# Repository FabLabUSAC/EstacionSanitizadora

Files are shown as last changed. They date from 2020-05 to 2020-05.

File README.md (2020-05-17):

# EstacionSanitizadora
EL objetivo es brindar un debido proceso de sanitizacion en las entradas de edificion concurridos, esto de manera automatizada para evitar que las personas infrijan las medidas de seguridad sanitarias establecidas por el evento actual de la pandemia del COVID-19.
En la contruccion final del prototipo se utilizaron los siguientes materiales:

2 puentes H L298N
Arduino Mega ADK
Lcd 16x2 con interfaz I2C serial
Fuente de 12V 5A
4 metros de tiras led verdes de exterior
4 metros de tiras led rojas de exterior
1 sensor ultrasonico hc-sr05
4 sensores de proximidad infrarrojos  
cable dupont macho macho, hembra hembra ,macho hembra
cable del calibre 22
Perfiles 20x20
Caja para proyectos
tornillos 3M
Tubo para cable

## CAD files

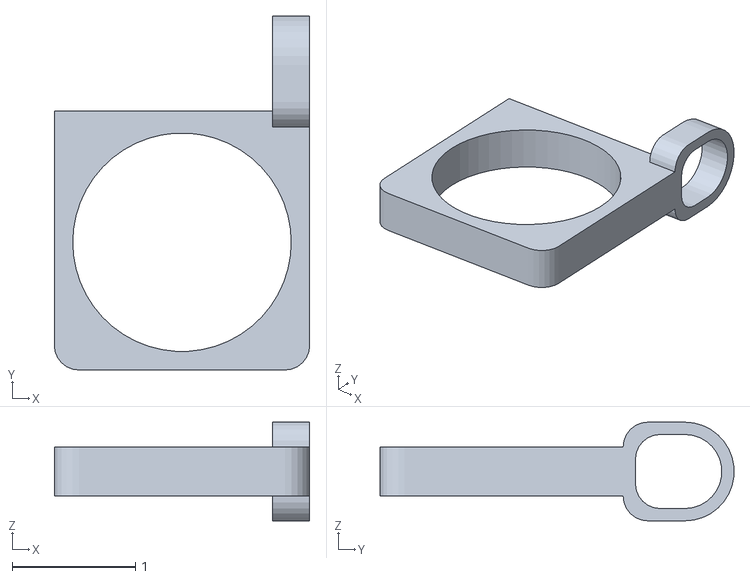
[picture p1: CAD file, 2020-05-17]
3D Files/Socket Sensor.stl
2.07 x 2.87 x 0.8

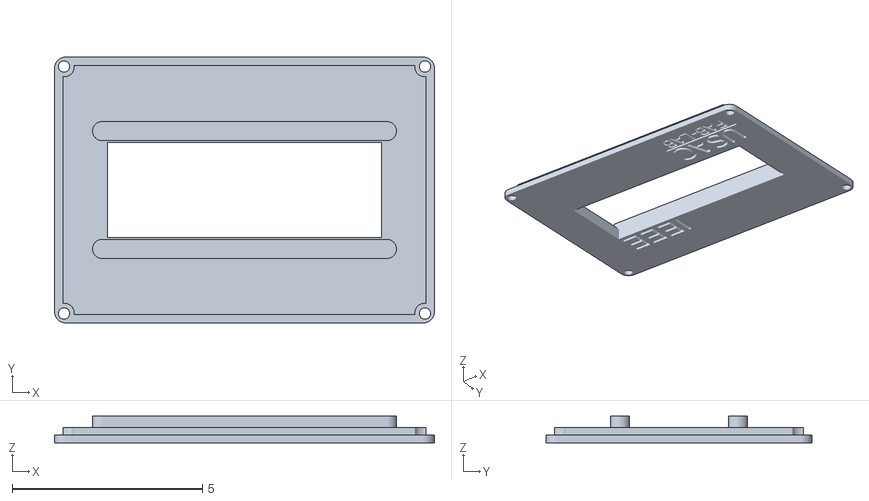
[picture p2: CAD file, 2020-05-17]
3D Files/Front_Box.stl
10.0 x 7.00 x 0.7

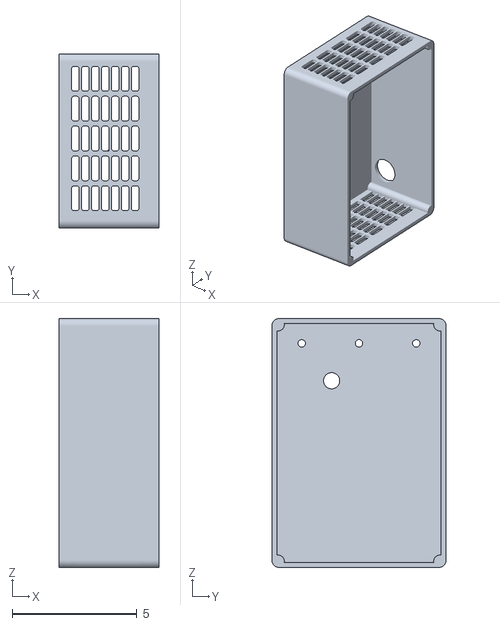
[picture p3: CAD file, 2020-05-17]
3D Files/Box.stl
4.00 x 7.00 x 10.0

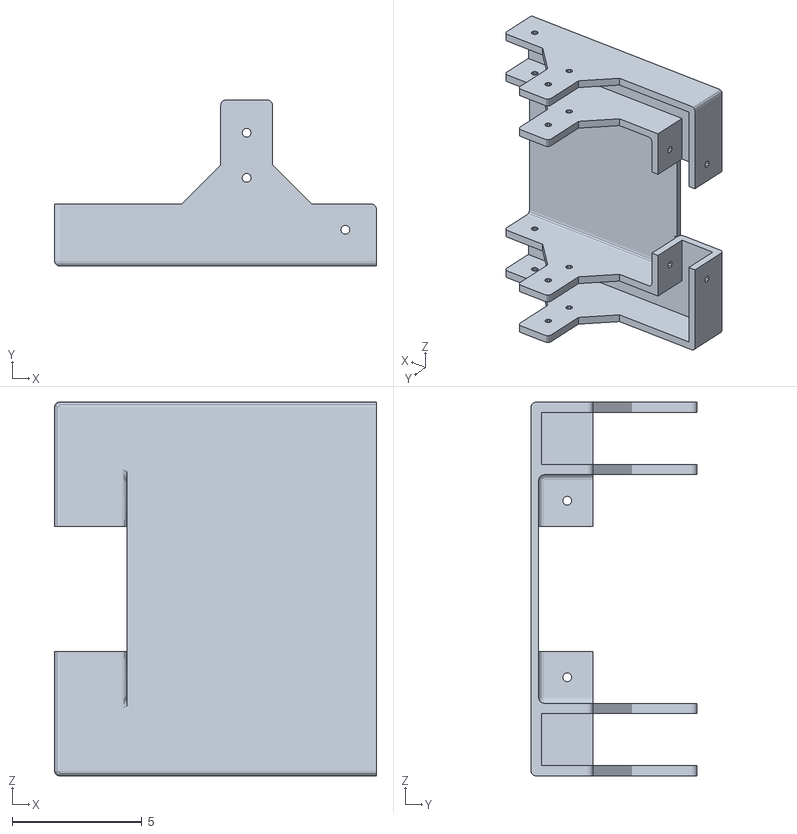
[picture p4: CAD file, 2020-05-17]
3D Files/Base.stl
12.4 x 6.40 x 14.4

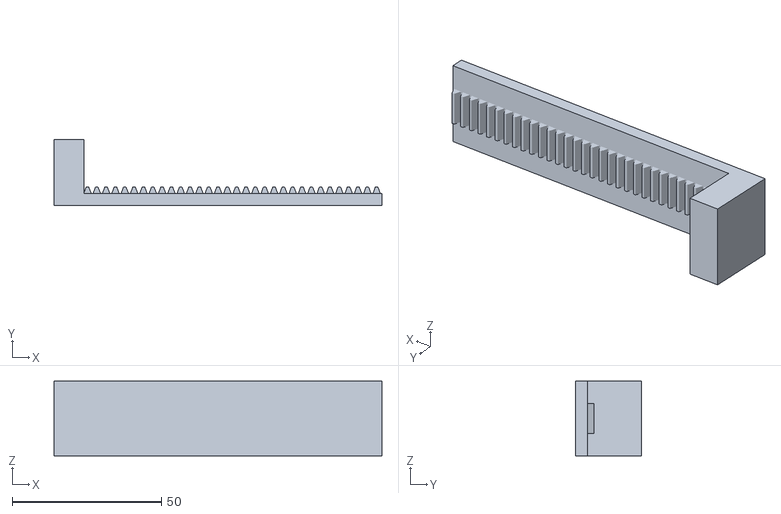
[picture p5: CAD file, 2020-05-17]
3D Files/Rack.stl
110.0 x 22.0 x 25.0

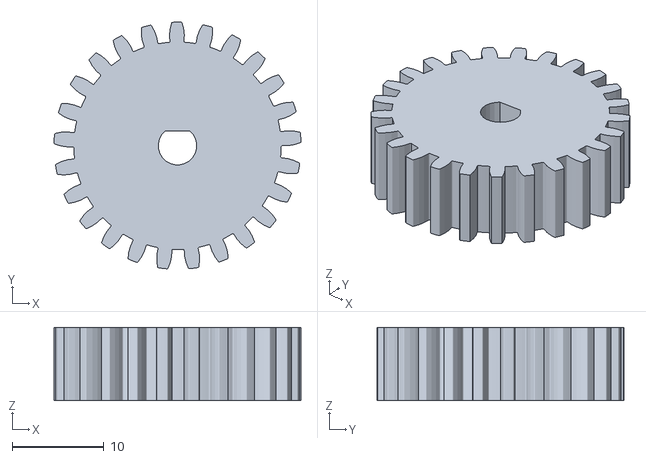
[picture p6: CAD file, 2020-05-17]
3D Files/Pinion.stl
27.0 x 27.0 x 8.00

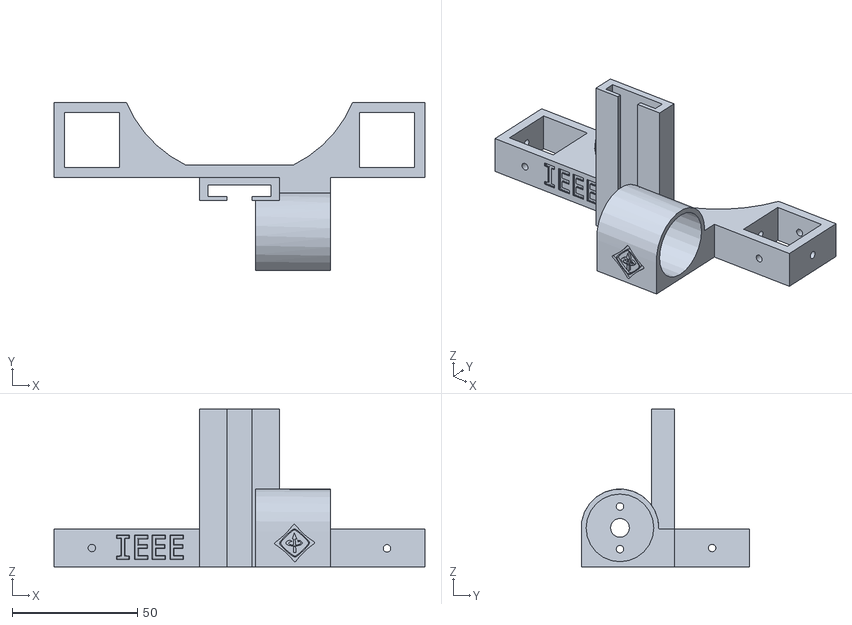
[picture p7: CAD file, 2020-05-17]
3D Files/Bracket_motor.stl
148.0 x 67.2 x 62.9

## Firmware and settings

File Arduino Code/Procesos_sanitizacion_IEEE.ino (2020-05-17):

/*IMPLEMENTAR LA PROGRA DEL DISPENSADOR
  IMPLEMENTAR DIAGRAMA DE ESTADOS*/
#include <pt.h>

#define ENTRA 13
#define SALE 12
#define BANDEJA_1 2
#define BANDEJA_2 3

// LCD
#include <Wire.h>
#include <LiquidCrystal_I2C.h>

LiquidCrystal_I2C lcd (0x27, 16, 2);

//HILOS
struct pt hilo_error;
struct pt hilo_verde1;
struct pt hilo_rojo1;
struct pt hilo_verde2;
struct pt hilo_rojo2;

//ULTRASONICO
int trig = 40;
int echo = 41;

int vpower1 = 12;
// variables
String linea;
int conteo = 0;

// motor
int ida = 38;
int vuelta = 39;

//PERMISOS DE ESTADOS
int permiso_entrada = 0;
int permiso_Bandeja1 = 0;
int permiso_Bandeja2 = 0;
int permiso_buzzer = 0;
int una_vez_buz = 0;

//PINES DE LAS TIRAS LED
int Verde_1 = 8;
int Rojo_1 = 9;
int Verde_2 = 10;
int Rojo_2 = 11;

//BANDERAS PARA CONTROL DE SENSORES
int flag_entra = 0;
int flag_sale = 0;
int flag_ban_1 = 0;
int flag_ban_2 = 0;

//VARIABLES GLOBALES
int num_personas = 0;
int i = 0;
int estado = 0;


//PINES Y VARIABLES PARA EL BUZZER
const int PinBuzzer = 5;
int PermisoBuzzer = 0;

// note durations: 4 = quarter note, 8 = eighth note, etc.:
int noteDurations[] = {
  4, 4, 4, 4,
  4, 4, 4, 4,
  4, 4, 4, 4,
};

void Conteo_Personas() {
  int E = digitalRead(ENTRA);

  if (E == 0 && flag_entra == 0) {
    num_personas = num_personas + 1;
    flag_entra = 1;
    estado = 1;
    permiso_entrada = 1;
    Serial.println("Concede Permiso Entrada");
  } else if (E == 1 && flag_entra == 1) {
    flag_entra = 0;
  }
}

void Deteccion_Bandeja_1(int permiso_entrada) {
  if (permiso_entrada == 1) {
    int Ban_1 = digitalRead(BANDEJA_1);
    if (Ban_1 == 0 && flag_ban_1 == 0) {
      flag_ban_1 = 1;
      estado = 2;
      permiso_Bandeja1 = 1;
      Serial.println("Concede Permiso Bandeja 1");
    } else if (Ban_1 == 1 && flag_ban_1 == 1) {
      flag_ban_1 = 0;
    }
  } else {
    estado = 666;
    Error(&hilo_error);
    Serial.println("Error Bandeja 1");
  }
}

void Deteccion_Bandeja_2(int permiso_Bandeja1) {
  if (permiso_Bandeja1 == 1) {
    int Ban_2 = digitalRead(BANDEJA_2);
    if (Ban_2 == 0 && flag_ban_2 == 0) {
      flag_ban_2 = 1;
      estado = 3;
      permiso_Bandeja2 = 1;
      una_vez_buz = 0;
      Serial.println("Concede Permiso Bandeja 2");
    } else if (Ban_2 == 1 && flag_ban_2 == 1) {
      flag_ban_2 = 0;
    }
  } else {
    estado = 666;
    Error(&hilo_error);
    Serial.println("Error Bandeja 2");
  }
}

void Buzzer(int permiso_Bandeja2) {
  if (una_vez_buz == 0) {
    Serial.println("IF");
    int j = 0;
    while (j < 3) {
      tone(5, 500);
      delay(150);
      noTone(5);
      delay(150);
      j += 1;
    }
    digitalWrite(5, HIGH);
    una_vez_buz = 1;
    estado = 4;
  }
}

void Dispensador() {
  long duracion;
  long distancia;

  digitalWrite(trig, LOW);
  delayMicroseconds(4);
  digitalWrite(trig, HIGH);
  delayMicroseconds(10);
  digitalWrite(trig, LOW);

  duracion = pulseIn(echo, HIGH); //1000 microsegundos = 1 milisegundo
  duracion = duracion / 2;
  distancia = duracion / 29;


  if (distancia <= 10) {

    Serial.println(distancia);
    conteo = conteo + 1;
    linea = "Utilizado: " + String(conteo) + " =)";
    lcd.setCursor(0, 1);
    lcd.print(linea);

    digitalWrite(ida, HIGH);
    digitalWrite(vuelta, LOW);
    delay(1000);
    digitalWrite(ida, LOW);
    digitalWrite(vuelta, LOW);
    delay(500);
    digitalWrite(ida, LOW);
    digitalWrite(vuelta, HIGH);
    delay(1000);
    digitalWrite(ida, LOW);
    digitalWrite(vuelta, LOW);
    estado = 0;
    una_vez_buz = 0;
  }
}

void Error(struct pt *pt) {
  PT_BEGIN(pt);// Aqui inicia mi protothread
  static long t = 0;
  digitalWrite(Verde_1, LOW);
  digitalWrite(Rojo_1, HIGH);
  digitalWrite(Verde_2, LOW);
  digitalWrite(Rojo_2, HIGH);

  t = millis();
  PT_WAIT_WHILE(pt, (millis() - t) < 1000); //delay(500);

  digitalWrite(Verde_1, LOW);
  digitalWrite(Rojo_1, LOW);
  digitalWrite(Verde_2, LOW);
  digitalWrite(Rojo_2, LOW);

  t = millis();
  PT_WAIT_UNTIL(pt, (millis() - t) > 1000); //delay(500);

  digitalWrite(Verde_1, LOW);
  digitalWrite(Rojo_1, HIGH);
  digitalWrite(Verde_2, LOW);
  digitalWrite(Rojo_2, HIGH);
  PT_END(pt);
}

void Breathing(int PIN_SALIDA, struct pt *pt) {
  PT_BEGIN(pt);
  static long t = 0;
  for (i = 15 ; i <= 255; i += 1)
  {
    analogWrite(PIN_SALIDA, i);
    if (i > 254) {
      t = millis();
      PT_WAIT_WHILE(pt, (millis() - t) < 2); //delay(2);
    }
    if ((i > 214) && (i < 255)) {
      t = millis();
      PT_WAIT_WHILE(pt, (millis() - t) < 4); //delay(4);
    }
    if (( i > 171) && (i < 215)) {
      t = millis();
      PT_WAIT_WHILE(pt, (millis() - t) < 5); //delay(5);
    }
    if (( i > 128) && (i < 172)) {
      t = millis();
      PT_WAIT_WHILE(pt, (millis() - t) < 9); //delay(9);
    }
    if (( i > 85) && (i < 129)) {
      t = millis();
      PT_WAIT_WHILE(pt, (millis() - t) < 12); //delay(12);
    }
    if (( i > 42) && (i < 86)) {
      t = millis();
      PT_WAIT_WHILE(pt, (millis() - t) < 14); //delay(14);
    }
    if (( i > 1) && (i < 43)) {
      t = millis();
      PT_WAIT_WHILE(pt, (millis() - t) < 15); //delay(15);
    }
  }
  for (i = 255; i >= 15; i -= 1)
  {
    analogWrite(PIN_SALIDA, i);
    if (i > 254) {
      t = millis();
      PT_WAIT_WHILE(pt, (millis() - t) < 2); //delay(2);
    }
    if ((i > 214) && (i < 255)) {
      t = millis();
      PT_WAIT_WHILE(pt, (millis() - t) < 4); //delay(4);
    }
    if (( i > 171) && (i < 215)) {
      t = millis();
      PT_WAIT_WHILE(pt, (millis() - t) < 5); //delay(5);
    }
    if (( i > 128) && (i < 172)) {
      t = millis();
      PT_WAIT_WHILE(pt, (millis() - t) < 9); //delay(9);
    }
    if (( i > 85) && (i < 129)) {
      t = millis();
      PT_WAIT_WHILE(pt, (millis() - t) < 12); //delay(12);
    }
    if (( i > 42) && (i < 86)) {
      t = millis();
      PT_WAIT_WHILE(pt, (millis() - t) < 14); //delay(14);
    }
    if (( i > 1) && (i < 43)) {
      t = millis();
      PT_WAIT_WHILE(pt, (millis() - t) < 15); //delay(15);
    }
  }
 // delay(1);
  t = millis();
  PT_WAIT_WHILE(pt, (millis() - t) < 2); //delay(2);

  PT_END(pt);
}

void setup() {
  //PINES PARA LOS SENSORES DE PROXIMIDAD
  Serial.begin(9600);
  pinMode(ENTRA, INPUT_PULLUP);
  pinMode(SALE, INPUT_PULLUP);
  pinMode(BANDEJA_1, INPUT_PULLUP);
  pinMode(BANDEJA_2, INPUT_PULLUP);

  //INICIALIZACION DE LOS HILOS PARA EL CONTROL DE LUCES
  PT_INIT(&hilo_error);
  PT_INIT(&hilo_verde1);
  PT_INIT(&hilo_rojo1);
  PT_INIT(&hilo_verde2);
  PT_INIT(&hilo_rojo2);

  //SET DE LAS TIRAS LED
  digitalWrite(Verde_2, LOW);
  digitalWrite(Verde_1, LOW);
  digitalWrite(Rojo_1, HIGH); //Breathing(Rojo_1, &hilo_rojo1);  
  digitalWrite(Rojo_2, HIGH); //Breathing(Rojo_2, &hilo_rojo2);  
  

  //v power
  pinMode(vpower1, OUTPUT);
  digitalWrite(vpower1, HIGH);

  // lcd
  lcd.init();
  lcd.backlight();
  lcd.clear();
  lcd.setCursor(0, 0);
  lcd.print("===hola_USAC===");

  // sensor
  pinMode(trig, OUTPUT);
  pinMode(echo, INPUT);

  // motor
  pinMode(ida, OUTPUT);
  pinMode(vuelta, OUTPUT);
}

void loop() {

  switch (estado) {

    //ENTRADA
    case 0:
      Conteo_Personas();
      break;

    //BANDEJA_1
    case 1:
      digitalWrite(Verde_1, HIGH);
      digitalWrite(Rojo_1, LOW);
      digitalWrite(Verde_2, LOW);
      digitalWrite(Rojo_2, HIGH);
      Serial.println("Entra al metodo de Bandeja1");
      Deteccion_Bandeja_1(permiso_entrada);
      break;

    //BANDEJA_2
    case 2:
      digitalWrite(Verde_1, LOW);
      digitalWrite(Rojo_1, HIGH);
      digitalWrite(Verde_2, HIGH);
      digitalWrite(Rojo_2, LOW);
      Deteccion_Bandeja_2(permiso_Bandeja1);
      break;

    //BUZZER
    case 3:
      digitalWrite(Verde_1, LOW);
      digitalWrite(Rojo_1, HIGH);
      digitalWrite(Verde_2, LOW);
      digitalWrite(Rojo_2, HIGH);
      Buzzer(permiso_Bandeja2);
      break;

    //DISPENSADOR
    case 4:
      Dispensador();
      break;

    default:
      Error(&hilo_error);
      break;
  }
  delay(10);
}

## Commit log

2020-05-17 Create Arduino Code
2020-06-12 Se agrego la carpeta de Documentation que contiene la carta para la IEEE donde se detalle acerca del proyecto, falta agregarle la factura con los gastos.
